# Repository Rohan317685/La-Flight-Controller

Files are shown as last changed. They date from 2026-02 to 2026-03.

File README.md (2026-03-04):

I present you fira:
A flight controller!
I have made a accurate ish render of the frame we have spent somewhat weeks its just we were trying to make sure it was affordable and have some lists for kits this could be in!
It has 4 s12302 Mosfets and a esp32-s3-wroom-1 controller and can be controlled entirely via WIFI!

I attached a render of what it can be used for :) Its meant for simple tiny drones!



That is the schematic + pcb!
Credits to:

@Rohan for creating the render, schematic and repo
@traffic person for routing the entire pcb and helping with technical issues!

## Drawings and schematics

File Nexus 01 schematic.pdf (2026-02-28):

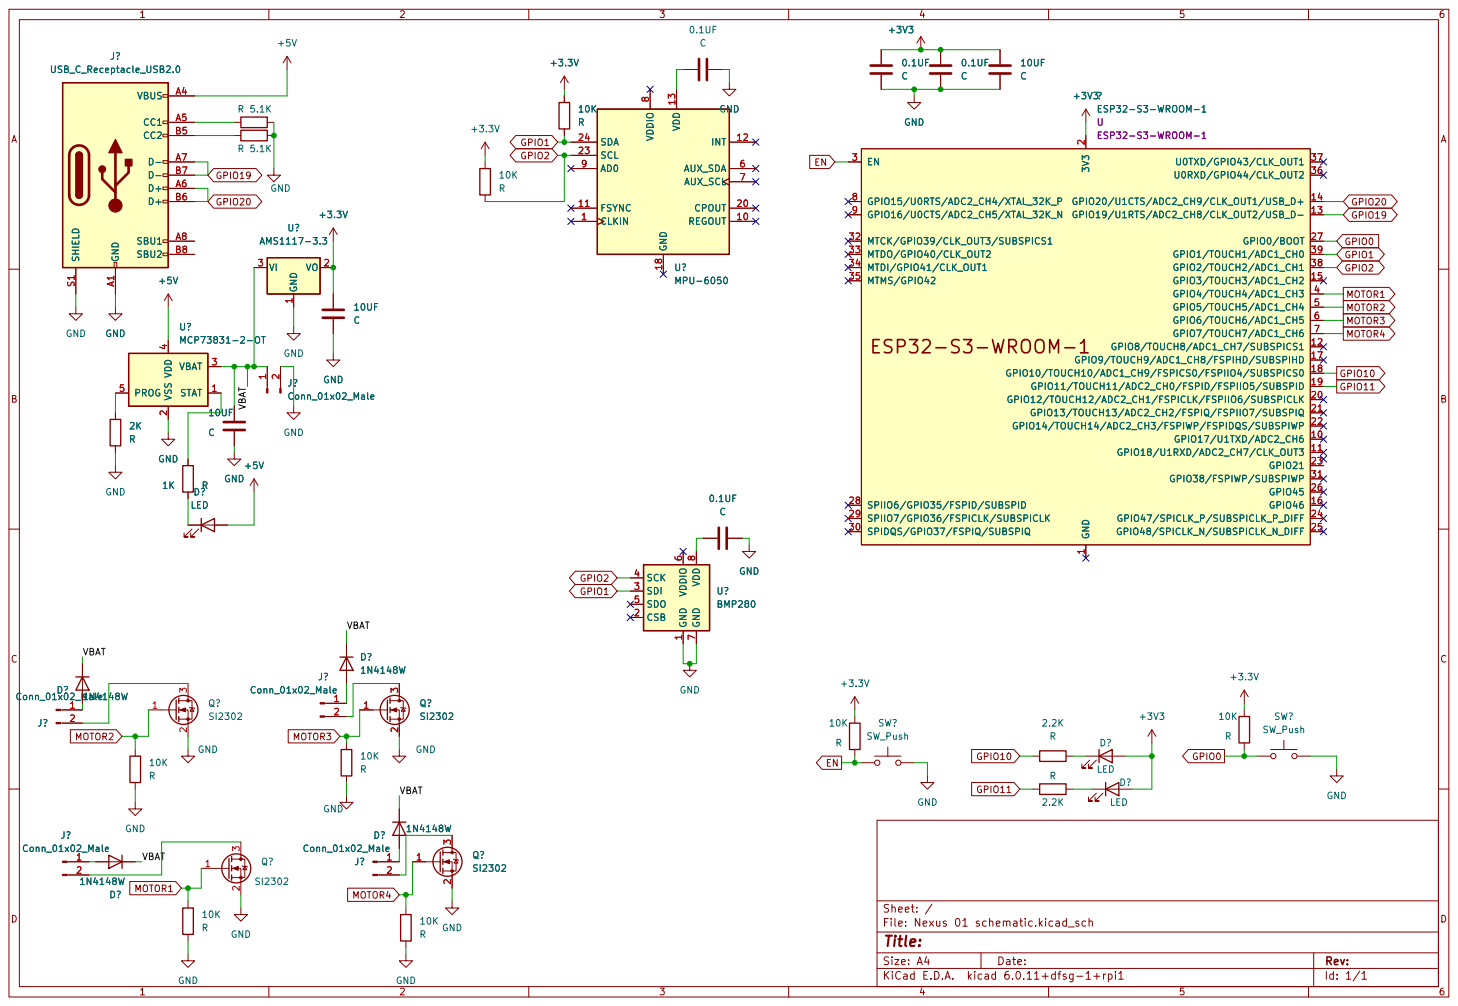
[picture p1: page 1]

2 3 Q? SI2302 GND GND A1 VBUS A4 CC1 A5 D+ A6 D- A7 SBU1 A8 CC2 B5 D+ B6 D- B7 SBU2 B8 SHIELD S1

2 GPIO12/TOUCH12/ADC2_CH1/FSPICLK/FSPIIO6/SUBSPICLK 20 GPIO13/TOUCH13/ADC2_CH2/FSPIQ/FSPIIO7/SUBSPIQ 21 GPIO14/TOUCH14/ADC2_CH3/FSPIWP/FSPIDQS/SUBSPIWP 22 GPIO21 23 GPIO47/SPICLK_P/SUBSPICLK_P_DIFF 24 GPIO48/SPICLK_N/SUBSPICLK_N_DIFF 25 GPIO45 26 GPIO0/BOOT 27 SPIIO6/GPIO35/FSPID/SUBSPID 28 SPIIO7/GPIO36/FSPICLK/SUBSPICLK 29 EN

1 GPIO17/U1TXD/ADC2_CH6 10 GPIO18/U1RXD/ADC2_CH7/CLK_OUT3 11 GPIO8/TOUCH8/ADC1_CH7/SUBSPICS1 12 GPIO19/U1RTS/ADC2_CH8/CLK_OUT2/USB_D- 13 GPIO20/U1CTS/ADC2_CH9/CLK_OUT1/USB_D+ 14 GPIO3/TOUCH3/ADC1_CH2 15 GPIO46 16 GPIO9/TOUCH9/ADC1_CH8/FSPIHD/SUBSPIHD 17 GPIO10/TOUCH10/ADC1_CH9/FSPICS0/FSPIIO4/SUBSPICS0 18 GPIO11/TOUCH11/ADC2_CH0/FSPID/FSPIIO5/SUBSPID 19 3V3

1 CSB 2 SDI 3 SCK 4 SDO 5 VDDIO

Id: 1/1 Title: File: Nexus 01 schematic.kicad_sch Sheet: /

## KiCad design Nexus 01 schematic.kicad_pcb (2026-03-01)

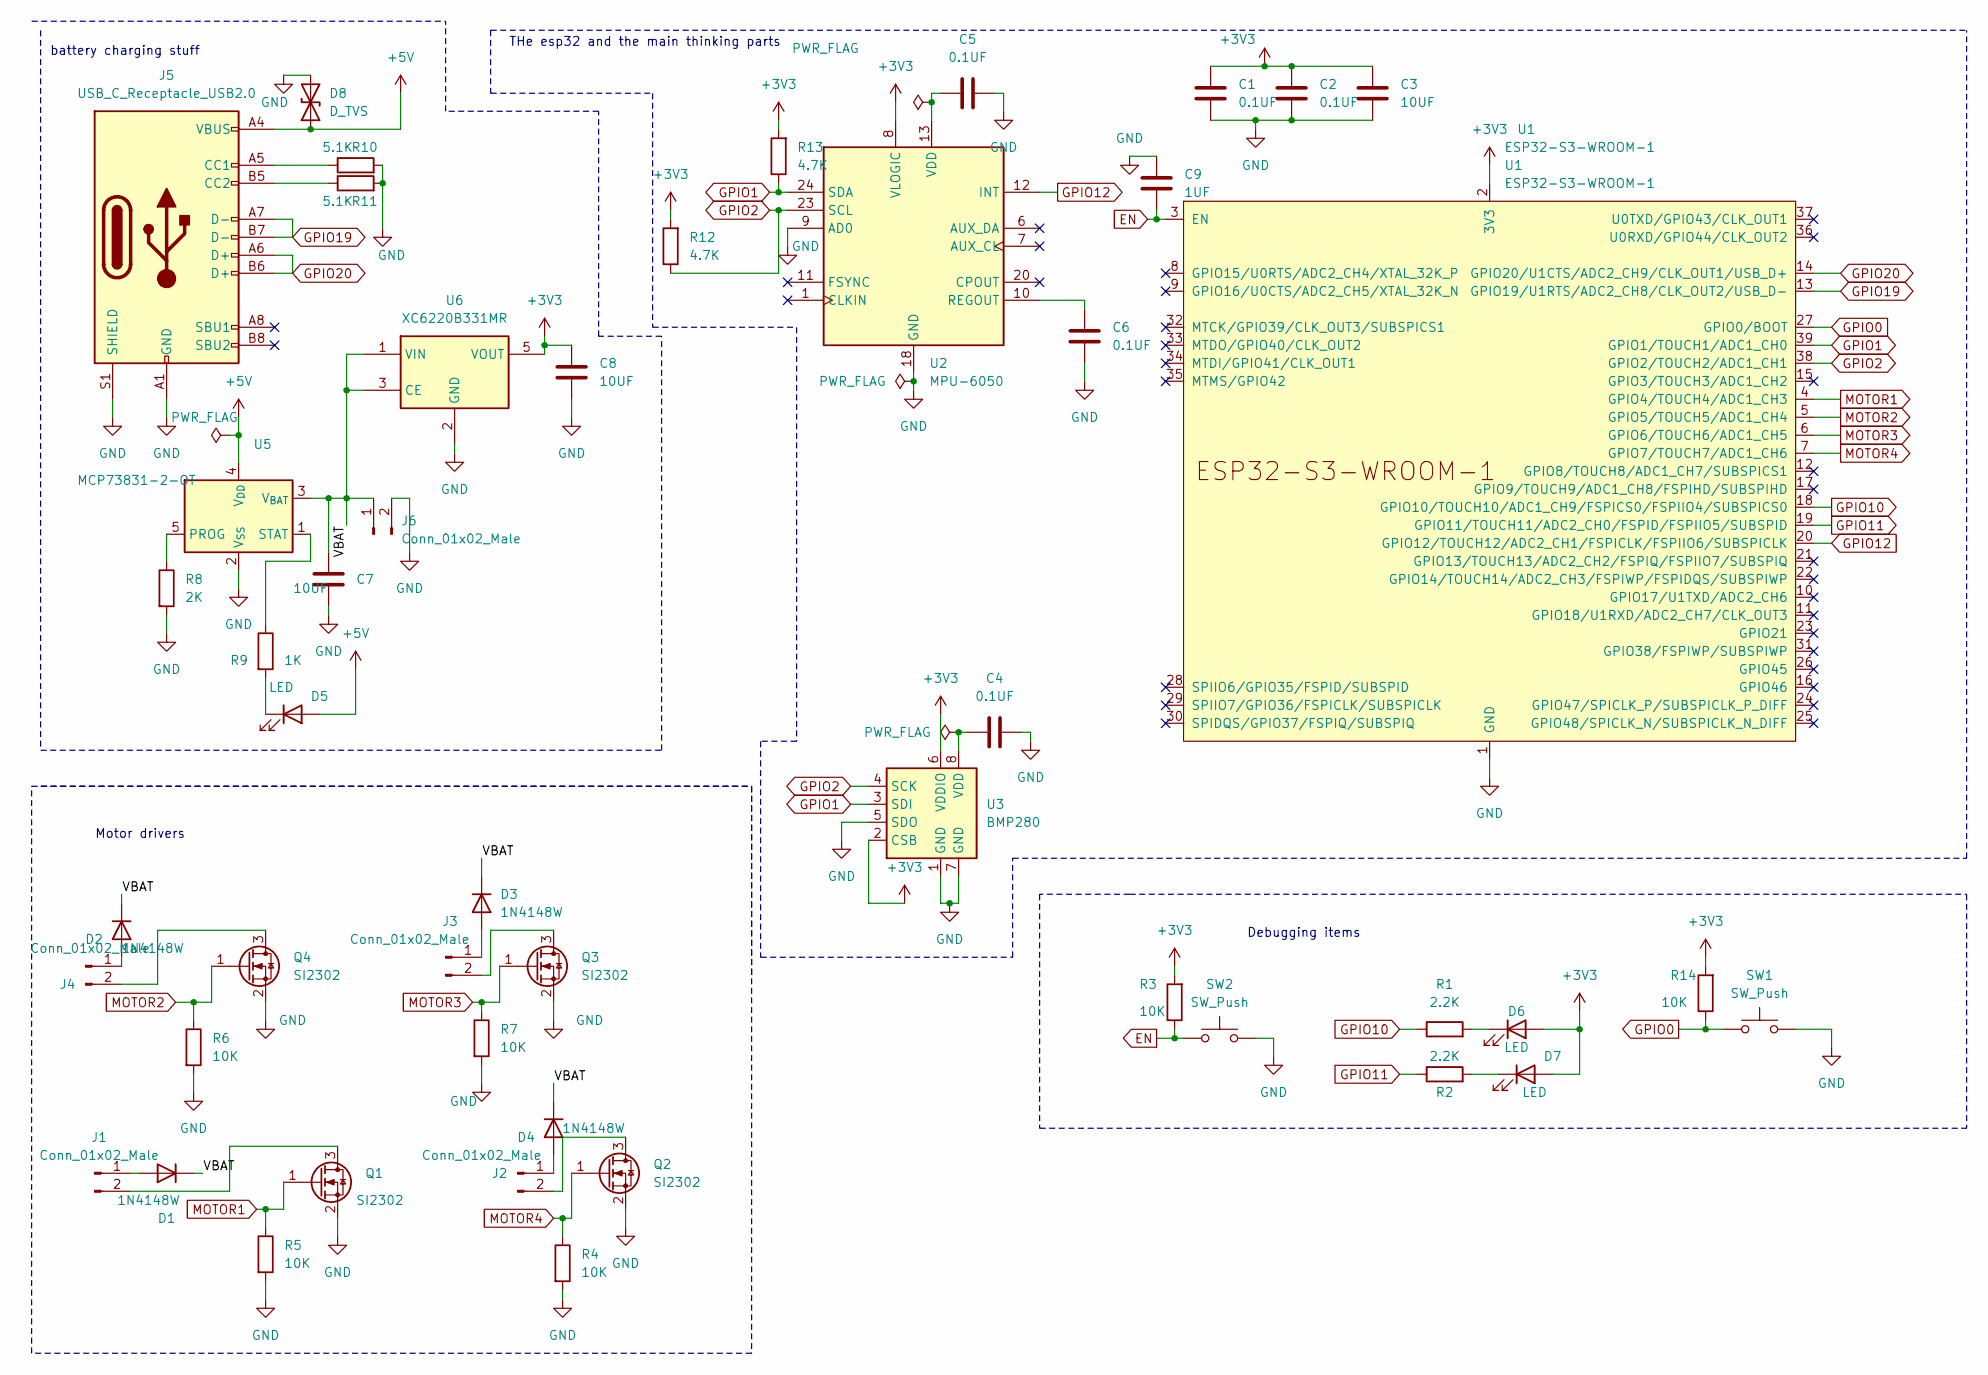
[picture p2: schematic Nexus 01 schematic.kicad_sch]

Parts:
C1, C2, C4, C5, C6: 0.1UF; C_0603_1608Metric
C3, C7, C8: 10UF; C_0805_2012Metric
C9: 1UF; C_0603_1608Metric
D1, D2, D3, D4: 1N4148W; D_SOD-123
D5, D6, D7: LED; LED_0603_1608Metric
D8: D_TVS; D_SOD-323
J1, J2, J3, J4, J6: Conn_01x02_Male; PinHeader_1x02_P1.00mm_Vertical
J5: USB_C_Receptacle_USB2.0; USB_C_Receptacle_HRO_TYPE-C-31-M-12
Q1, Q2, Q3, Q4: SI2302; SOT-23
R1, R2: 2.2K; R_0603_1608Metric
R3, R4, R5, R6, R7, R14: 10K; R_0603_1608Metric
R8: 2K; R_0603_1608Metric
R9: 1K; R_0603_1608Metric
R10, R11: 5.1K; R_0603_1608Metric
R12, R13: 4.7K; R_0603_1608Metric
SW1, SW2: SW_Push; SW_Push_1TS009xxxx-xxxx-xxxx_6x6x5mm
U1: ESP32-S3-WROOM-1
U2: MPU-6050; InvenSense_QFN-24_4x4mm_P0.5mm
U3: BMP280; Bosch_LGA-8_2x2.5mm_P0.65mm_ClockwisePinNumbering
U5: MCP73831-2-OT; SOT-23-5
U6: XC6220B331MR; SOT-23-5

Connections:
+3V3: C1.1, C2.1, C3.1, C8.1, D6.2 (A), D7.2 (A), R3.2, R12.2, R13.2, R14.2, U1.2 (3V3), U2.8 (VLOGIC), U3.2 (CSB), U3.6 (VDDIO), U6.5 (VOUT)
+5V: D5.2 (A), D8.1 (A1), J5.A4 (VBUS), J5.A9 (VBUS), J5.B4 (VBUS), J5.B9 (VBUS), U5.4 (V_{DD})
/VBAT: C7.1, D1.1 (K), D2.1 (K), D3.1 (K), D4.1 (K), J6.1, U5.3 (V_{BAT}), U6.1 (VIN), U6.3 (CE)
EN: C9.2, R3.1, SW2.1, U1.3 (EN)
GND: C1.2, C2.2, C3.2, C4.1, C5.2, C6.2, C7.2, C8.2, C9.1, D8.2 (A2), J5.A1 (GND), J5.A12 (GND), J5.B1 (GND), J5.B12 (GND), J5.S1 (SHIELD), J6.2, Q1.2 (S), Q2.2 (S), Q3.2 (S), Q4.2 (S), R4.2, R5.2, R6.2, R7.2, R8.2, R10.2, R11.2, SW1.2, SW2.2, U1.1 (GND), U1.40 (GND), U1.41 (GND), U2.9 (AD0), U2.18 (GND), U3.1 (GND), U3.5 (SDO), U3.7 (GND), U5.2 (V_{SS}), U6.2 (GND)
GPIO0: R14.1, SW1.1, U1.27 (GPIO0/BOOT)
GPIO1: R13.1, U1.39 (GPIO1/TOUCH1/ADC1_CH0), U2.24 (SDA), U3.3 (SDI)
GPIO2: R12.1, U1.38 (GPIO2/TOUCH2/ADC1_CH1), U2.23 (SCL), U3.4 (SCK)
GPIO10: R1.1, U1.18 (GPIO10/TOUCH10/ADC1_CH9/FSPICS0/FSPIIO4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)
GPIO11: R2.1, U1.19 (GPIO11/TOUCH11/ADC2_CH0/FSPID/FSPIIO5/S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)
GPIO12: U1.20 (GPIO12/TOUCH12/ADC2_CH1/FSPICLK/FSPIIO6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), U2.12 (INT)
GPIO19: J5.A7 (D-), J5.B7 (D-), U1.13 (GPIO19/U1RTS/ADC2_CH8/CLK_OUT2/USB_D-)
GPIO20: J5.A6 (D+), J5.B6 (D+), U1.14 (GPIO20/U1CTS/ADC2_CH9/CLK_OUT1/USB_D+)
MOTOR1: Q1.1 (G), R5.1, U1.4 (GPIO4/TOUCH4/ADC1_CH3)
MOTOR2: Q4.1 (G), R6.1, U1.5 (GPIO5/TOUCH5/ADC1_CH4)
MOTOR3: Q3.1 (G), R7.1, U1.6 (GPIO6/TOUCH6/ADC1_CH5)
MOTOR4: Q2.1 (G), R4.1, U1.7 (GPIO7/TOUCH7/ADC1_CH6)
unnamed: D1.2 (A), J1.1
unnamed: D2.2 (A), J4.1
unnamed: D3.2 (A), J3.1
unnamed: D4.2 (A), J2.1
unnamed: D5.1 (K), R9.2
unnamed: D6.1 (K), R1.2
unnamed: D7.1 (K), R2.2
unnamed: J1.2, Q1.3 (D)
unnamed: J2.2, Q2.3 (D)
unnamed: J3.2, Q3.3 (D)
unnamed: J4.2, Q4.3 (D)
unnamed: J5.A5 (CC1), R10.1
unnamed: J5.B5 (CC2), R11.1
unnamed: C6.1, U2.10 (REGOUT)
unnamed: C5.1, U2.13 (VDD)
unnamed: C4.2, U3.8 (VDD)
unnamed: R8.1, U5.5 (PROG)
unnamed: R9.1, U5.1 (STAT)

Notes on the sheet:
THe esp32 and the main thinking parts
Motor drivers
battery charging stuff
Debugging items

Board: 4 copper layers, 48 parts (0 on the bottom side), 35 nets, no tracks yet.
